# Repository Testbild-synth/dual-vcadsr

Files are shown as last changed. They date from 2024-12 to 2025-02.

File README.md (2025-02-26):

# Eurorack DUAL Voltage controlled AR / ADSR / LFO / Random / S&H Utility Module

This project is a dual utility module on the basis of an Arduino nano that does a bunch of neat things.
It is fully through hole and has relatively standard parts (safe for maybe the DAC module but you can get that on aliexpress)

## Status
Has been built by multiple people and works fine! 
I have gotten complaints about small holes for the pushbuttons so I created a V1.1 with 
bigger holes in the PCB and the panel to allow a wider variety of pushbutton parts.

## Hardware and PCB

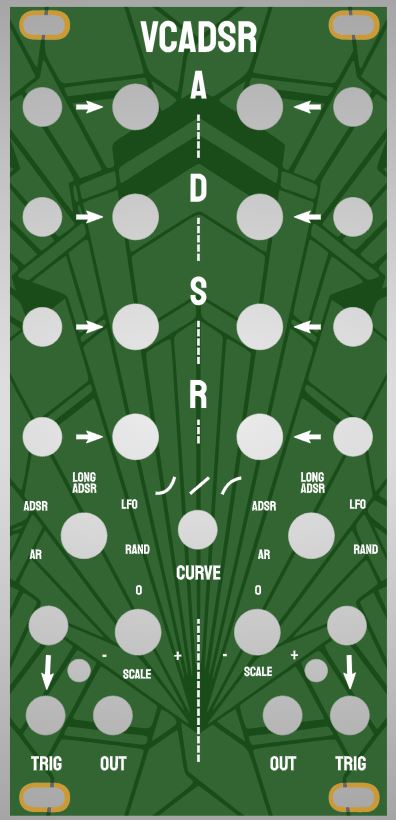
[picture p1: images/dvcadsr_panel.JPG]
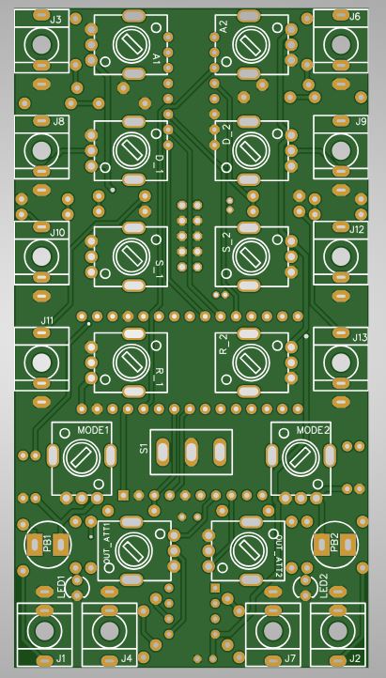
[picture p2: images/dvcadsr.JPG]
 

The module has one Panel PCB and one circuit PCB, relatively straight forward, just order with standard settings on jlcpcb or any other pcb site.
The build is relatively straight forward, but there is one spot at the top where the IC and pot kind of overlap a bit. be sure
to not have stuff standing out too much from the IC so that it contacts the metal housing of the pots and shorts. should be doable

## Status
Has been built by multiple people and works fine! 
I have gotten complaints about small holes for the pushbuttons so I created a V1.1 with 
bigger holes in the PCB and the panel to allow a wider variety of pushbutton parts.

## Code

The code is under the firmware folder and can be uploaded to the nano using the arduino IDE.
For the MUX chip it uses the "Analog digital Multiplexers" library found here: [source repo](https://github.com/stechio/arduino-ad-mux-lib?tab=readme-ov-file) ,
[arduino libraries page](https://docs.arduino.cc/libraries/analog-digital-multiplexers/).
You can get it from the library browser inside arduino IDE.

## Operation
In general, to make it easier on myself I have wired it such that the CV replaces knob values so the knobs are useless if something is plugged in.
In my experience this is not that much of a problem as you usually either want to dial in a specific shape or have an lfo etc plugged in.
The cool (at least I think it's cool) thing is that you can change CV during a phase to affect the progession of the current phase.

The modules has the following modes:
 - Attack-release: When triggered, does an attack, then a release
 - Attack-Decay-sustain-release: When triggered, does ADSR as a normal envelope would. 
 - Long Attack-Decay-sustain-release: as normal ADSR but longer by a factor 10
 - LFO: Goes from Attack to Decay to release immediately, then back to attack. Trigger retriggers the attack stage
 - RAND: Random values. Attack Pot changes minimum value, Decay pot changes value range. Each trigger gives a new value. **By plugging in CV to attack and setting Decay pot to 0 you can use it as a sample/hold which I think is very neat!** Sustain pot quantizes to one of six scales, but this is a bit experimental and might now work perfectly since all output is scaled by the scale pot and by arduino internal 5V conversion anyways.

 Curve switch switches between linear, exponential and logarithmic. This is the one thing shared by both channels otherwise they operate independently.

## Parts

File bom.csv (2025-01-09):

ID | Name | Designator | Footprint | Quantity
1 | 100k Potentiometer | A1,A2,D_1,D_2,MODE1,MODE2,R_1,R_2,S_1,S_2,OUT_ATT1,OUT_ATT2 | R09k potentiometer | 12
2 | Eurorack jacks Thonkiconn |  | Eurorack jack Thonkiconn | 12
14 | LED TBR | LED1,LED2 | LED-3MM/2.54 | 2
15 | TRIG1 | PB1, PB2 | Pushbutton NORMALLY OPEN 6mm | 1 | like this footprint but NO version https://makerselectronics.com/product/round-momentary-push-button-switch-on-off-normally-closed-2pin-ac-125v-1a-nb-602-red-7mm
17 | SPDT | S1 | TOGGLE SWITCH SPDT RED 3 PIN ON-OFF-ON 3 SPDT SMALL AC 6A/125V 3A/250V | 1
18 | 10u | C1,C2 | CAP-D4.0×F1.5 | 2
19 | 100n | C3,C4 | RAD-0.1 | 2
20 | Schottky diode (BAT43) | D1,D2,D3,D4 | DO-34_BD1.6-L3.0-P7.00-D0.6-RD | 4
21 | Power header | EP1 | EURORACK_POWER_V2 | 1
22 | MCP4728 | J5 | this thing: https://eckstein-shop.de/GY-MCP472812BitDigitaltoAnalogConverterDACEvaluationBoard?gQT=2 or similar footprint | 1
23 | 1k | R1,R2,R4,R13 | R_AXIAL-0.3 | 4
24 | 200k | R3,R11 | R_AXIAL-0.3 | 2
25 | 100k | R5,R15 | R_AXIAL-0.3 | 2
26 | 47k | R6,R12,R17,R19,R21,R22,R25,R26 | R_AXIAL-0.3 | 8
27 | 10k | R7,R16 | R_AXIAL-0.3 | 2
28 | 3k3 | R8,R10 | R_AXIAL-0.3 | 2
29 | 33k | R9,R14,R18,R20,R23,R24,R27,R28 | R_AXIAL-0.3 | 8
30 | CD74HC4051_THT_DIP-16 | U1 | CD74HC4051_THT_DIP-16 | 1
31 | TL072 | U3 | DIP8 | 1

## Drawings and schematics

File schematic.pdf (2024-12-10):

# S1 10 S0 11 A3 12 A0 13 A1 14 A2 15 VCC 16

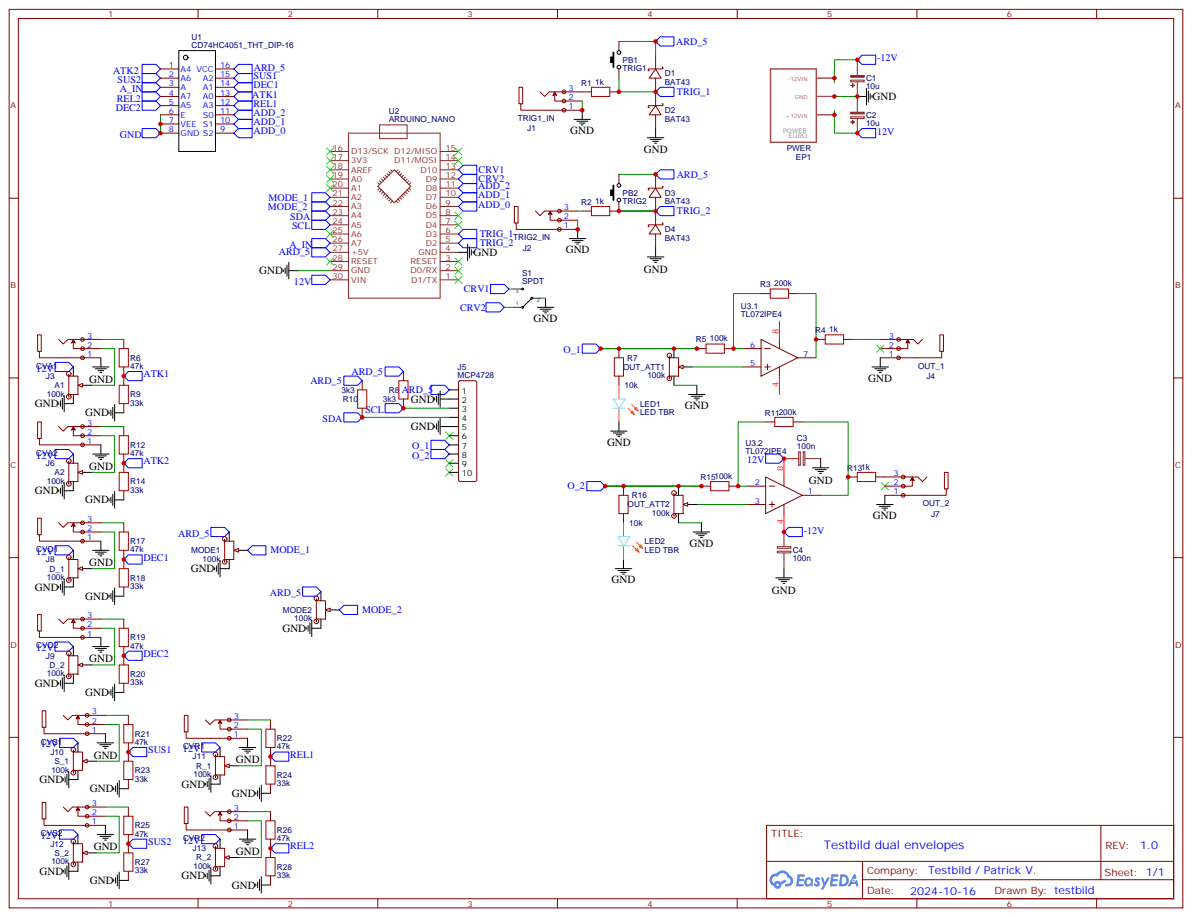
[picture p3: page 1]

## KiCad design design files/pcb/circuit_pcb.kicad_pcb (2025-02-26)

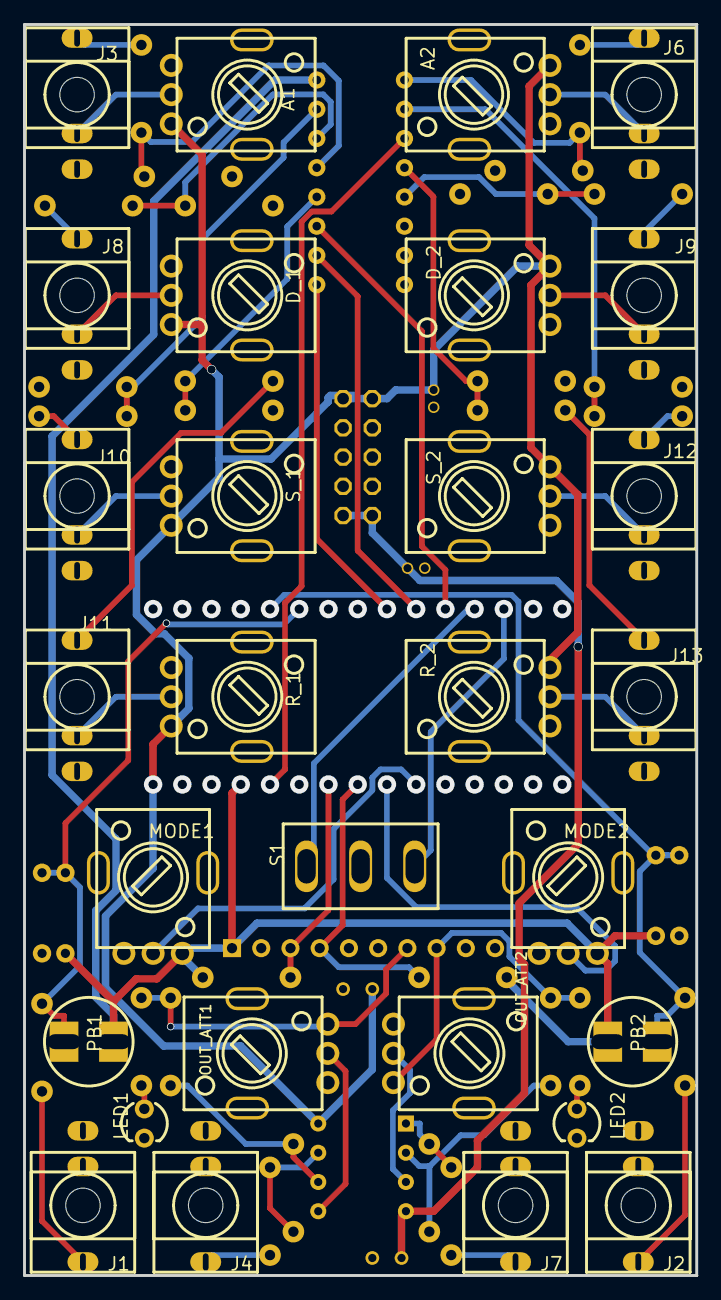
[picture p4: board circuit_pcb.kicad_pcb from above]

Board: 2 copper layers, 58.4 x 108.7 mm, 69 parts (0 on the bottom side), 46 nets.

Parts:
A1, A2: 100k; R09-5KΩ
C1, C2: 10u; CAP-D4.0×F1.5
C3, C4: 100n; RAD-0.1
D1, D2, D3, D4: S; DO-34_BD1.6-L3.0-P7.00-D0.6-RD
D_1, D_2: 100k; R09-5KΩ
EP1: PWER; EURORACK_POWER_V2
J1: TRIG1_IN; THONKICONN_1
J2: TRIG2_IN; THONKICONN_1
J3: CVA1; THONKICONN_1
J4: OUT_1; THONKICONN_1
J5: MCP4728; HDR-M-2.54_1X10
J6: CVA2; THONKICONN_1
J7: OUT_2; THONKICONN_1
J8: CVD1; THONKICONN_1
J9: CVD2; THONKICONN_1
J10: CVS1; THONKICONN_1
J11: CVR1; THONKICONN_1
J12: CVS2; THONKICONN_1
J13: CVR2; THONKICONN_1
LED1, LED2: LED TBR; LED-3MM/2.54
MODE1, MODE2: 100k; R09-5KΩ
OUT_ATT1, OUT_ATT2: 100k; R09-5KΩ
PB1: TRIG1; PUSHBUTTON
PB2: TRIG2; PUSHBUTTON
R1, R2, R4, R13: 1k; R_AXIAL-0.3
R3, R11: 200k; R_AXIAL-0.3
R5, R15: 100k; R_AXIAL-0.3
R6, R12, R17, R19, R21, R22, R25, R26: 47k; R_AXIAL-0.3
R7, R16: 10k; R_AXIAL-0.3
R8, R10: 3k3; R_AXIAL-0.3
R9, R14, R18, R20, R23, R24, R27, R28: 33k; R_AXIAL-0.3
R_1, R_2: 100k; R09-5KΩ
S1: SPDT; TOGGLE SWITCH SPDT RED 3 PIN ON-OFF-ON 3 SPDT SMALL AC 6A/1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
S_1, S_2: 100k; R09-5KΩ
U1: CD74HC4051_THT_DIP-16
U3: TL072; DIP8

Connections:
12V: A1.3, A2.3, C2.1, C3.1, D_1.3, D_2.3, EP1.12, R_1.3, R_2.3, S_1.3, S_2.3, U3.8
-12V: C1.2, C4.1, EP1.-12, U3.4
A2_2: A2.2, J6.2
ARD_5: D1.1, D3.1, J5.1, MODE1.3, MODE2.3, PB1.2, PB2.2, R8.1, R10.1, U1.16
ATK1: R6.1, R9.2, U1.13
ATK2: R12.1, R14.2, U1.1
DEC1: R17.1, R18.2, U1.14
DEC2: R19.1, R20.2, U1.5
GND: A1.1, A2.1, C1.1, C2.2, C3.2, C4.2, D2.2, D4.2, D_1.1, D_2.1, EP1.GND0, EP1.GND1, EP1.GND2, EP1.GND3, EP1.GND4, EP1.GND5, J1.1, J1.2, J2.1, J2.2, J3.1, J4.1, J5.2, J5.5, J6.1, J7.1, J8.1, J9.1, J10.1, J11.1, J12.1, J13.1, LED1.2, LED2.2, MODE1.1, MODE2.1, OUT_ATT1.1, OUT_ATT2.1, R9.1, R14.1, R18.1, R20.1, R23.1, R24.1, R27.1, R28.1, R_1.1, R_2.1, S1.2, S_1.1, S_2.1, U1.6, U1.7, U1.8
J3_2: A1.2, J3.2
J6_3: J6.3, R12.2
J7_3: J7.3, R13.1
J8_2: D_1.2, J8.2
J9_2: D_2.2, J9.2
J10_2: J10.2, S_1.2
J11_3: J11.3, R22.2
J12_3: J12.3, R25.2
J13_2: J13.2, R_2.2
LED1_1: LED1.1, R7.2
O_1: J5.7, OUT_ATT1.3, R5.2, R7.1
O_2: J5.8, OUT_ATT2.3, R15.2, R16.1
R1_2: J1.3, R1.2
R2_2: J2.3, R2.2
R4_1: J4.3, R4.1
R6_2: J3.3, R6.2
R16_2: LED2.1, R16.2
R17_2: J8.3, R17.2
R19_2: J9.3, R19.2
R21_2: J10.3, R21.2
R26_2: J13.3, R26.2
REL1: R22.1, R24.2, U1.12
REL2: R26.1, R28.2, U1.4
R_1_2: J11.2, R_1.2
SCL: J5.3, R8.2
SDA: J5.4, R10.2
SUS1: R21.1, R23.2, U1.15
SUS2: R25.1, R27.2, U1.2
S_2_2: J12.2, S_2.2
TRIG_1: D1.2, D2.1, PB1.1, R1.1
TRIG_2: D3.2, D4.1, PB2.1, R2.1
U3_1: R11.1, R13.2, U3.1
U3_2: R11.2, R15.1, U3.2
U3_3: OUT_ATT2.2, U3.3
U3_5: OUT_ATT1.2, U3.5
U3_6: R3.2, R5.1, U3.6
U3_7: R3.1, R4.2, U3.7

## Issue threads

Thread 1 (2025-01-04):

thanks

dtk1985, 2025-01-04:
Hi, thanks for the design 😃  I built it today, it works great after a quick testing. I have no sequencer yet so the random mode was really useful for driving your Arduino Triple VCO module.
I had to drill out the two holes for the momentary switches on the front panel to 7mm, because the switches I got from [aliexpress](https://www.aliexpress.com/item/32804945328.html) had a diameter of 6,8mm at the threaded part.
I also noticed that the silkscreen on the back of the panel is mirrored horizontally, at least that is how I got it from JLCPCB lol.

Testbild-synth, 2025-01-04:
Hi! thanks, always happy to see people building and using my designs. Regarding the silkscreen, not sure I wanna make a change and I seem to have ruined my inkscape file...
My switches seemd to work without drilling I think, but if others complain maybe there will be a revision.
If you have issues with or suggestions for the firmware let me know and I will make an update!

Tilmanfs95, 2025-02-21:
I really want to express my sincere thanks for this module. The build was very straightforward, and after a quick test, it works flawlessly. The button issue was the same for me, but it was absolutely no problem and easily fixed. The module is truly fantastic, and I'm very happy with it.
If you want I can create a pull request with a picture of my build in the next days
Thank you so much :)

Testbild-synth, 2025-02-26:
heyhey, thanks to the both of you for your kind words, always happy to see my modules being built by other people. I have uploaded a version with 7.2mm holes instead of 6.2mm holes for the pushbuttons. If you have suggestions for software improvements let me know!

Closed 2025-02-26.

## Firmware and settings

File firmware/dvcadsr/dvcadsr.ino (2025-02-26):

// dvcasr software
#include "Mux.h"
#include <Adafruit_MCP4728.h>
#include <Wire.h>

// uses "Analog digital Multiplexers" library https://docs.arduino.cc/libraries/analog-digital-multiplexers/
// https://github.com/stechio/arduino-ad-mux-lib?tab=readme-ov-file
using namespace admux;
Mux mux(Pin(A7, INPUT, PinType::Analog), Pinset(8, 7, 6));
Adafruit_MCP4728 mcp;

// pin definitions
#define TRIG1_PIN 3
#define TRIG2_PIN 2
#define MODE1_PIN A2
#define MODE2_PIN A3
#define CRV1_PIN 10
#define CRV2_PIN 9

// possible states of AR/adsr
enum State {
  ATTACK,   
  DECAY,    
  SUSTAIN,  
  RELEASE,
  OFF, 
};

// operation mode
enum Mode {
  AR,
  ADSR,
  LONG_ADSR,
  LFO,
  RAND
};

Mode current_modes[2] = {AR,AR};
State current_states[2] = {OFF,OFF};

// internal states: duty cycle from 0 to 200. Last cycle start time is kept, as starting value for current cycle
// which is needed to calculate sustain and release steps
float last_cycle_start[2] = {0,0};
uint8_t current_cycle_positions[2] = {0,0};
float cycle_start_values[2] = {0,0};

// current values for output
float current_values[2] = {0,0};

// current trigger state
bool triggers_on[2] = {false, false};

float settings[8] = {512,512,512,512,512,512,512,512};

// constants for duty cycle
const static uint16_t LOG[200] = {
 0,  64, 93, 122,  150,  177,  203,  228,  253,  277,  299,  322,  343,  364,  384,  404,  423,  441,  459,  476,  493,  509,  524,  539,  554,  568,  582,  595,  608,  620,  632,  644,  655,  666,  677,  687,  697,  707,  716,  725,  734,  742,  751,  759,  766,  774,  781,  788,  795,  801,  808,  814,  820,  825,  831,  836,  842,  847,  852,  856,  861,  865,  870,  874,  878,  882,  886,  889,  893,  896,  900,  903,  906,  909,  912,  915,  917,  920,  923,  925,  928,  930,  932,  934,  937,  939,  941,  942,  944,  946,  948,  950,  951,  953,  954,  956,  957,  959,  960,  961,  963,  964,  965,  966,  967,  968,  969,  970,  971,  972,  973,  974,  975,  976,  977,  978,  978,  979,  980,  980,  981,  982,  982,  983,  984,  984,  985,  985,  986,  986,  987,  987,  988,  988,  988,  989,  989,  990,  990,  990,  991,  991,  991,  992,  992,  992,  993,  993,  993,  993,  994,  994,  994,  994,  995,  995,  995,  995,  995,  996,  996,  996,  996,  996,  997,  997,  997,  997,  997,  997,  997,  998,  998,  998,  998,  998,  998,  998,  998,  998,  999,  999,  999,  999,  999,  999,  999,  999,  999,  999,  999,  999,  999,  1000, 1000, 1000, 1000, 1000, 1000, 1000
};
const static uint16_t RAMP[200] = {
 0,  10, 15, 20, 25, 30, 35, 40, 45, 50, 55, 60, 65, 70, 75, 80, 85, 90, 95, 100,  105,  110,  115,  120,  125,  130,  135,  140,  145,  150,  155,  160,  165,  170,  175,  180,  185,  190,  195,  200,  205,  210,  215,  220,  225,  230,  235,  240,  245,  250,  255,  260,  265,  270,  275,  280,  285,  290,  295,  300,  305,  310,  315,  320,  325,  330,  335,  340,  345,  350,  355,  360,  365,  370,  375,  380,  385,  390,  395,  400,  405,  410,  415,  420,  425,  430,  435,  440,  445,  450,  455,  460,  465,  470,  475,  480,  485,  490,  495,  500,  505,  510,  515,  520,  525,  530,  535,  540,  545,  550,  555,  560,  565,  570,  575,  580,  585,  590,  595,  600,  605,  610,  615,  620,  625,  630,  635,  640,  645,  650,  655,  660,  665,  670,  675,  680,  685,  690,  695,  700,  705,  710,  715,  720,  725,  730,  735,  740,  745,  750,  755,  760,  765,  770,  775,  780,  785,  790,  795,  800,  805,  810,  815,  820,  825,  830,  835,  840,  845,  850,  855,  860,  865,  870,  875,  880,  885,  890,  895,  900,  905,  910,  915,  920,  925,  930,  935,  940,  945,  950,  955,  960,  965,  970,  975,  980,  985,  990,  995,  1000
};
const static uint16_t EXP[200] = {
 0,  0,  0,  0,  0,  0,  1,  1,  1,  1,  1,  1,  1,  1,  1,  1,  1,  1,  1,  2,  2,  2,  2,  2,  2,  2,  2,  2,  3,  3,  3,  3,  3,  3,  3,  4,  4,  4,  4,  4,  5,  5,  5,  5,  5,  6,  6,  6,  6,  7,  7,  7,  7,  8,  8,  8,  9,  9,  9,  10, 10, 10, 11, 11, 12, 12, 12, 13, 13, 14, 14, 15, 15, 16, 16, 17, 18, 18, 19, 20, 20, 21, 22, 22, 23, 24, 25, 26, 27, 28, 29, 30, 31, 32, 33, 34, 35, 36, 37, 39, 40, 41, 43, 44, 46, 47, 49, 50, 52, 54, 56, 58, 59, 61, 63, 66, 68, 70, 72, 75, 77, 80, 83, 85, 88, 91, 94, 97, 100,  104,  107,  111,  114,  118,  122,  126,  130,  135,  139,  144,  148,  153,  158,  164,  169,  175,  180,  186,  192,  199,  205,  212,  219,  226,  234,  241,  249,  258,  266,  275,  284,  293,  303,  313,  323,  334,  345,  356,  368,  380,  392,  405,  418,  432,  446,  461,  476,  491,  507,  524,  541,  559,  577,  596,  616,  636,  657,  678,  701,  723,  747,  772,  797,  823,  850,  878,  907,  936,  967,  1000
};

// constants for quantization
const uint16_t note_values[61] = {0, 68, 136, 205, 273, 341, 410, 478, 546, 614, 682, 751, 819, 887, 956, 1024, 1092, 1160, 1228, 1297, 1365, 1433, 1502, 1570, 1638, 1706, 1774, 1843, 1911, 1979, 2048, 2116, 2184, 2252, 2320, 2389, 2457, 2525, 2594, 2662, 2730, 2798, 2866, 2935, 3003, 3071, 3140, 3208, 3276, 3344, 3412, 3481, 3549, 3617, 3686, 3754, 3822, 3890, 3958, 4027, 4095};
const uint8_t scales[8][12] = {{0, 1, 2, 3, 4, 5, 6, 7, 8, 9, 10, 11}, //chromatic
  {0, 0, 2, 2, 4, 5, 5, 7, 7, 9, 9 , 11}, //major
  {0, 0, 2, 3, 3, 5, 5, 7, 8, 8, 10, 10}, //minor
  {0, 0, 2, 3, 3, 5, 5, 7, 7, 9, 9, 11}, //melodic minor
  {0, 0, 0, 3, 3, 5, 6, 7, 7, 9, 9, 11}, //blues
  {0, 0, 0, 3, 3, 5, 5, 7, 7, 7, 10, 10}, // pentatonic
  {0, 0, 0, 0, 0, 0, 0, 7, 7, 7, 12, 12}, //oct and quint
  {0, 0, 0, 0, 0, 0, 0, 12, 12, 12, 12, 12} // oct
}; //oct
uint8_t scale_select[2] = {0,0};
uint8_t note_select[2] = {0,0};

void check_trigs(){
  if(digitalRead(TRIG1_PIN)!=triggers_on[0]){
    triggers_on[0] = digitalRead(TRIG1_PIN);
    delay(5); // software debounce before starting new cycle
    check_cycle_trig(0);
  }
  if(digitalRead(TRIG2_PIN)!=triggers_on[1]){
    triggers_on[1] = digitalRead(TRIG2_PIN);
    delay(5); // software debounce before starting new cycle
    check_cycle_trig(1);
  }
}

// start new state in cycle and reset values
void start_cycle_state(int ch, State state){
  last_cycle_start[ch] = millis();
  current_states[ch] = state;
  current_cycle_positions[ch] = 0;
  cycle_start_values[ch] = current_values[ch];
}

void update_random_value(int ch){
  // random update logic: min value is attack pot, range is decay pot, 
  // scale is sustain pot
  scale_select[ch] = round(settings[ch+2] / 128);
  current_values[ch] = random(settings[ch], min(settings[ch]+ settings[ch+1], 4095));
  if (scale_select[ch] != 0) {
    note_select[ch] = constrain(int((current_values[ch] / 67)),0,60);
    note_select[ch] = note_select[ch] - note_select[ch] % 12  + scales[scale_select[ch]][note_select[ch] % 12];
    current_values[ch] = note_values[note_select[ch]];
  }
}

// ceck if we should trigger a new cycle depending on trigger
void check_cycle_trig(int ch){
  if(triggers_on[ch]){
    if(current_modes[ch]==RAND){
      update_random_value(ch);
    }
    else{
      start_cycle_state(ch, ATTACK);
    }
  }
}

// loop through mux channels and read all potentiometers
void read_pot_vals(){
  for(int i=0; i<8; i++){
    settings[i] = mux.read(i);
  }
}

// cycle state switching logic for AR
void switch_cycle_AR(int ch){
  if(current_states[ch] == ATTACK){
      start_cycle_state(ch, RELEASE); 
    }
    else{
      start_cycle_state(ch, OFF);
    }
}

// cycle state switching logic for LFO. 
void switch_cycle_LFO(int ch){
  if(current_states[ch] == OFF ||current_states[ch] == RELEASE){
    start_cycle_state(ch, ATTACK);
  }
  else if(current_states[ch] == ATTACK){
    start_cycle_state(ch, DECAY);
  }
  else if(current_states[ch] == DECAY){
    start_cycle_state(ch, RELEASE);
  }
}

// cycle state switch logic for ADSR envelope
void switch_cycle_ADSR(int ch){
  if(current_states[ch] == ATTACK){
    if(triggers_on[ch]){
      start_cycle_state(ch, DECAY);
    }
    else{
      start_cycle_state(ch, RELEASE);
    }
  }
  else if (current_states[ch] == DECAY){
    if(triggers_on[ch]){
      start_cycle_state(ch, SUSTAIN);
    }
    else{
      start_cycle_state(ch, RELEASE);
    }
  }
  else if(current_states[ch] == SUSTAIN){
    if(!triggers_on[ch]){
      start_cycle_state(ch, RELEASE);
    }
  }
  else{
    start_cycle_state(ch, OFF);
  }
}

// switch cycle states. called at the end of a duty cycle to trigger the next state depending on current mode
void switch_cycle(int ch){
  if(current_modes[ch] == AR){
    switch_cycle_AR(ch);
  }
  else if(current_modes[ch] == ADSR || current_modes[ch] == LONG_ADSR){
    switch_cycle_ADSR(ch);
  }
  else if(current_modes[ch] == LFO){
    switch_cycle_LFO(ch);
  }
}

// udpate modes depending on potentiometer values
void update_modes(){
  Mode new_mode1 = static_cast<Mode>(int(analogRead(MODE1_PIN) / 230));
  Mode new_mode2 = static_cast<Mode>(int(analogRead(MODE2_PIN) / 230));
  if(current_modes[0] != new_mode1){
    current_modes[0] = new_mode1;
    start_cycle_state(0, OFF);
  }
  if(current_modes[1] != new_mode2){
    current_modes[1] = new_mode2;
    start_cycle_state(1, OFF);
  }
}

// select one of the curves for values. log exp or linear
uint16_t* select_curve(){
  if(!digitalRead(CRV2_PIN)){
    return LOG;
  }
  else if(!digitalRead(CRV1_PIN)){
    return EXP;
  }
  else{
    return RAMP;
  }
}

void update_output_value(int ch){
  // random mode: skip all other update just use stored value (updated in trig)
  if(current_modes[ch] == RAND){
    return;
  }
  uint16_t *active_curve = select_curve();
  
  if(current_states[ch] == ATTACK){
    current_values[ch] = 4*active_curve[current_cycle_positions[ch]];
    return;
  }
  else if(current_states[ch] == DECAY){
    // decay: difference between top and sustain level (settings 2 and 6);
    current_values[ch] = 4 * int(settings[4*ch + 2] + (active_curve[199-current_cycle_positions[ch]] * (1024.0-settings[4*ch + 2])/1024.0));
  }
  else if(current_states[ch] == SUSTAIN){
    current_values[ch] = cycle_start_values[ch];
  }
  else if(current_states[ch] == RELEASE){
    current_values[ch] =  int(cycle_start_values[ch] * float((active_curve[199-current_cycle_positions[ch]])/1000.0));
  }
  else{
    current_values[ch] = 0;
  }
}

void update_duty_cycle(int ch){
  if(current_states[ch] == SUSTAIN && !triggers_on[ch]){
    switch_cycle(ch);
  }
  else if(current_states[ch] != OFF || current_modes[ch]==LFO){
    if(current_modes[ch] == LONG_ADSR){
       current_cycle_positions[ch] = int(20*float(millis()-last_cycle_start[ch])/float(settings[ch*4 + current_states[ch]]+20));
    }
    else{
       current_cycle_positions[ch] = int(200*float(millis()-last_cycle_start[ch])/float(settings[ch*4 + current_states[ch]]+20));
    }
    if(current_cycle_positions[ch] > 199){
      switch_cycle(ch);
    }
  }
}

void setup() {
  while (!mcp.begin()) {
    delay(1000);
  }
  pinMode(CRV1_PIN, INPUT_PULLUP);
  pinMode(CRV2_PIN, INPUT_PULLUP);
  digitalWrite(CRV1_PIN, HIGH);
  digitalWrite(CRV2_PIN, HIGH);
  mcp.setChannelValue(MCP4728_CHANNEL_A,  4000);
  mcp.setChannelValue(MCP4728_CHANNEL_B,  4000);
  delay(500);
  mcp.setChannelValue(MCP4728_CHANNEL_A,  0);
  mcp.setChannelValue(MCP4728_CHANNEL_B,  0);
  delay(500);
  mcp.setChannelValue(MCP4728_CHANNEL_A,  4000);
  mcp.setChannelValue(MCP4728_CHANNEL_B,  4000);
  delay(500);
  mcp.setChannelValue(MCP4728_CHANNEL_A,  0);
  mcp.setChannelValue(MCP4728_CHANNEL_B,  0);
  delay(500);
}

void loop() {
  read_pot_vals();
  update_modes();
  check_trigs();
  update_duty_cycle(0);
  update_duty_cycle(1);
  update_output_value(0);
  update_output_value(1);
  mcp.setChannelValue(MCP4728_CHANNEL_A,  current_values[0]);
  mcp.setChannelValue(MCP4728_CHANNEL_B, current_values[1]);
  delayMicroseconds(100);
  
}

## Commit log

2024-12-10 initial file upload
    [bom.csv, circuit_pcb.kicad_pcb]
2025-02-26 panel with bigger holes for pushbuttons
    [dvcadsr.kicad_pcb]
2025-02-26 V1.1 pcb (only changes are bigger switch holes and a nametag)
    [circuit_pcb.kicad_pcb]
